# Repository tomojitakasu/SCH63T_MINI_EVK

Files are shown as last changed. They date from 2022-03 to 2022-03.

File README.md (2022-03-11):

# **SCHA63T_MINI_EVK**

## **Overview**

SCHA63T_MINI_EVK is a compact USB 2.0 interface board for Murata 6 DOF MEMS-IMU
SCHA63T-K03. The IMU sensor sampling timing can be synchronized by PPS and
NMEA inputs from an external clock source.

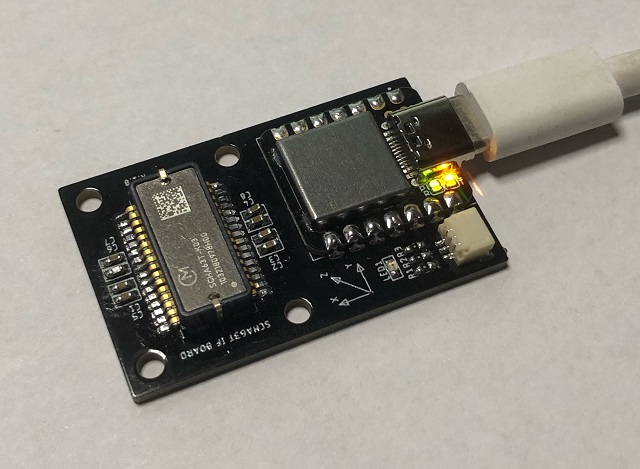
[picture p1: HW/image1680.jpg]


--------------------------------------------------------------------------------

## **Package Structure**
```
SCHA63T_MINI_EVK --+-- FW      Firmware source programs for Seeeduino XIAO
                   |           (ref [3])
                   +-- HW      I/F Board CAD data and parts list for hardware
                   |           (*.brd and *.sch are for Eagle)
                   +-- doc     SCHA63T-K03 documents (ref [1][2])
```

--------------------------------------------------------------------------------

## **Installation**

* Download and install Arduino IDE to your PC by "Software Step 1" in ref [3].

* Extract PocketSDR.zip to an appropriate directory <install_dir>.

* In Arduino IDE, execute menu File - Open... and select the sketch file
<install_dir>\SCHA63T_MIN_EVK\FW\Arduino\SCHA63T\SCHA63T.ino.

* Execute menu Sketch - Verify/Compile to compile the sketch.

* Connect SCHA63T_MINI_EVK board to the PC. Reset Seeeduino XIAO by shorting
the RST pins twice to enter the boot mode.

* Execute menu Tools - Board "Seeeduino XIAO" - Seeed SAMD (32-bits ARM
Cortex-M0+ and Cortex-M4) Boards - Seeeduino XIAO.

* Execute menu Tools - Port - COMxx (Seeeduino XIAO).

* Execute menu Sketch - Upload. If you see "Verify successful" in the IDE
message window, the firmware is properly written to the board.

--------------------------------------------------------------------------------

## **Operation**

* After connecting the SCHA63T_MINI_EVK board to the PC by USB cable, the board
automatically starts to output the IMU data as the following format via the USB
serial port. The initial output data rate is 100 Hz.
```
  $IMU,<t_sync>,<time>,<Rx>,<Ry>,<Rz>,<Ax>,<Ay>,<Az>,<temp>,<stat>*<CS>\r\n

  <t_sync>   : External time sync status (0:async, 1: PPS, 2: PPS + NMEA)
  <time>     : Time tag (s) (time of day in UTC for <t_sync> = 2)
  <Rx>,<Ry>,<Rz> : Gyroscope X,Y,Z data (deg/H)
  <Ax>,<Ay>,<Az> : Accelerometer X,Y,Z data (g)
  <temp>     : Sensor temperature (C)
  <stat>     : Sensor summary status (HEX) (0: OK, 1: error)
               bit 6-4: Rx,Ry,Rz, bit 2-0: Ax,Ay,Az
  <CS>       : Checksum same as NMEA
```

* By inputting PPS and NMEA signals via the external sync connector of the
board, the sampling timing of the IMU can be synchronized to the external
clock source. The pin assignment of the external sync connector is as follows.
Without the sync signals, the sampling is done by the internal clock.
```
  JST SH 3P (TOP VIEW)
  +-------+
  | pin 3 | <---- NMEA (3.3V, 9600 bps, GxGGA or GxRMC)
  | pin 2 | <---- PPS  (3.3V, rising edge)
  | pin 1 | ----- GND
  +-------+
```

* By sending commands to the board via the USB serial port, some IMU or
sampling parameters can be configured. The commands are as follows. The max
data rate is 200 Hz.
```
  reset                        : Reset device.
  device                       : Show device information.
  start                        : Start output data.
  stop                         : Stop output data.
  status                       : Show status.
  rate [<rate>]                : Set output data rate (Hz).
  range [<range_g> <range_a>]  : Select dynamic range gyro/accel.
                                 (0:300deg/H or 6g, 1:150deg/H or 1.5g)
  filter [<filt_g> <filt_a>]   : Select filter gyro/accel.
                                 (0:13Hz, 1:20Hz, 2:46Hz, 3:200Hz, 4:300Hz)
  table                        : Show cross-axis compensation table.
  read {DUE|UNO} [<addr>]      : Read device register(s). (addr:HEX)
  write {DUE|UNO} <addr> <val> : Write device register. (addr/val:HEX)
  debug [<level>]              : Set debug level. (0:no debug)
  help                         : Show command help.
```

--------------------------------------------------------------------------------

## **References**

[1] Murata, SCHA63T-K03 Data Sheet, Rev 1, 2021

[2] Murata, Assembly instructions for SCHA600 series Technical Note Rev 1.0, 2021

[3] Seeed Wiki, Getting Started with Seeeduino XIAO
(https://wiki.seeedstudio.com/Seeeduino-XIAO)

--------------------------------------------------------------------------------

## **History**

- 2022-03-11  1.0  1st version

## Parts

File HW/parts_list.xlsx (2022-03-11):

No | Part | Value | Package | Supplier | Supplier Part Number | Digi-Key Part Number | URL
1 | IMU1 | SCHA63T-K03 | SOIC-32 | Murata | SCHA63T-K03-05 | 490-SCHA63T-K03-05CT-ND | https://www.digikey.jp/product-detail/ja/murata-electronics/SCHA63T-K03-05/490-SCHA63T-K03-05CT-ND/14309548
2 | U1 | MOUDLE-SEEEDUINO-XIAO | 21 x 17.8 mm, 14P-2.54 mm | Seeed | Seeediuino XIAO | - | https://wiki.seeedstudio.com/Seeeduino-XIAO/
3 | C1 | 1uF | C1608
4 | C2 | 1uF | C1608
5 | C3 | 100nF | C1608
6 | C4 | 1uF | C1608
7 | C5 | 1uF | C1608
8 | C6 | 100nF | C1608
9 | C7 | 1uF | C1608
10 | C8 | 1uF | C1608
11 | R1 | 1K | R1608
12 | R2 | 1K | R1608
13 | R3 | 1K | R1608
14 | LED1 | LED1608 | LED1608
15 | J1 | Conn Header SMD R/A 3P 1mm | 4.25 x 5.0 x 2.9 mm | JST | SM03B-SRSS-TB(LF)(SN) | 455-1803-1-ND | https://www.digikey.jp/product-detail/ja/jst-sales-america-inc/SM03B-SRSS-TB-LF-SN/455-1803-1-ND/926874

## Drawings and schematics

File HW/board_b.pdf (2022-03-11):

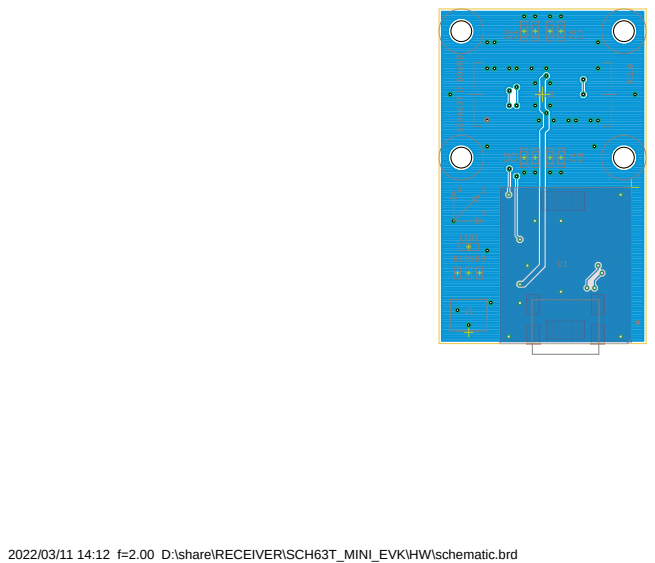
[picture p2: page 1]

2022/03/11 14:12 f=2.00 D:\share\RECEIVER\SCH63T_MINI_EVK\HW\schematic.brd

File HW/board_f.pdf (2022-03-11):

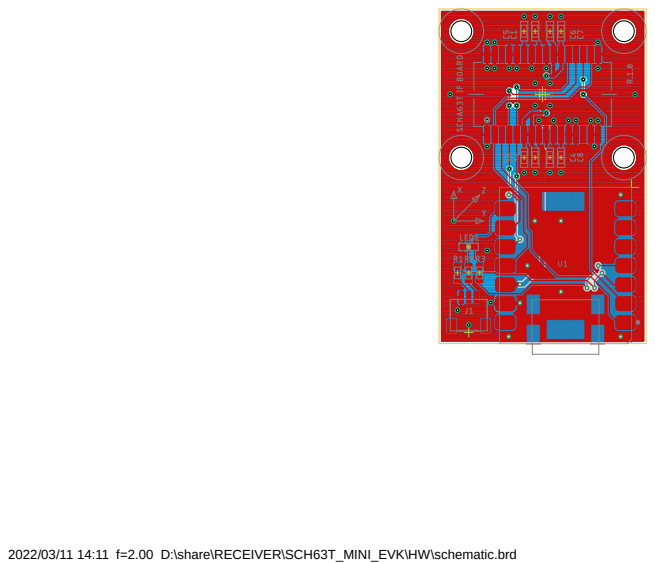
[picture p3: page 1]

2022/03/11 14:11 f=2.00 D:\share\RECEIVER\SCH63T_MINI_EVK\HW\schematic.brd

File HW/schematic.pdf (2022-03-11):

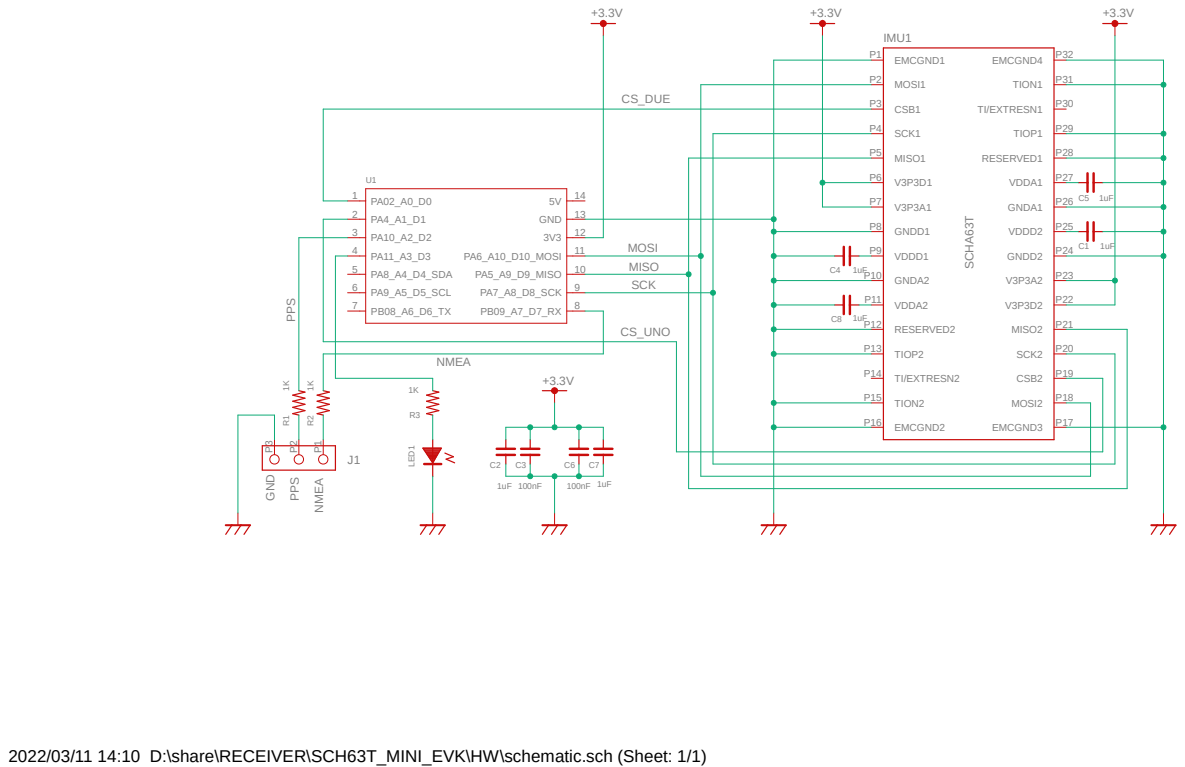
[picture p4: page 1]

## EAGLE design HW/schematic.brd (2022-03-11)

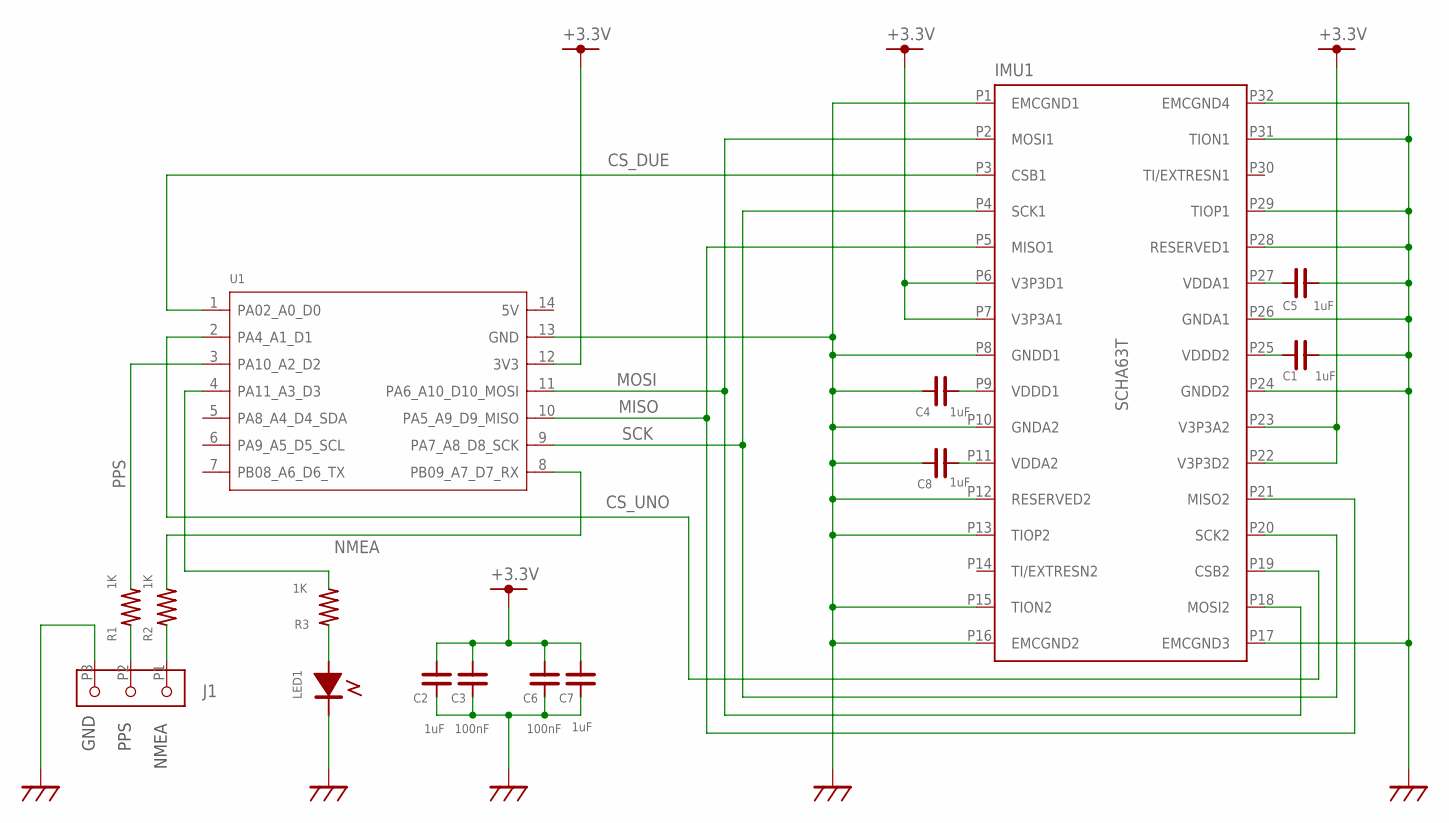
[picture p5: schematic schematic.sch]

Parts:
C1, C2, C4, C5, C7, C8: 1uF; C1608
C3, C6: 100nF; C1608
IMU1: SCHA63T; SOIC-32
J1: JST_SH_10_3P
LED1: LED1608; LED_1608
R1, R2, R3: 1K; C1608
U1: MOUDLE-SEEEDUINO-XIAO; MOUDLE14P-2.54-21X17.8MM

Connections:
+3.3V: C2.2, C3.2, C6.2, C7.2, IMU1.P6 (V3P3D1), IMU1.P7 (V3P3A1), IMU1.P22 (V3P3D2), IMU1.P23 (V3P3A2), U1.12 (3V3)
CS_DUE: IMU1.P3 (CSB1), U1.1 (PA02_A0_D0)
CS_UNO: IMU1.P19 (CSB2), U1.2 (PA4_A1_D1)
GND: C1.2, C2.1, C3.1, C4.1, C5.2, C6.1, C7.1, C8.1, IMU1.P1 (EMCGND1), IMU1.P8 (GNDD1), IMU1.P10 (GNDA2), IMU1.P12 (RESERVED2), IMU1.P13 (TIOP2), IMU1.P15 (TION2), IMU1.P16 (EMCGND2), IMU1.P17 (EMCGND3), IMU1.P24 (GNDD2), IMU1.P26 (GNDA1), IMU1.P28 (RESERVED1), IMU1.P29 (TIOP1), IMU1.P31 (TION1), IMU1.P32 (EMCGND4), J1.P3, LED1.2, U1.13 (GND)
MISO: IMU1.P5 (MISO1), IMU1.P21 (MISO2), U1.10 (PA5_A9_D9_MISO)
MOSI: IMU1.P2 (MOSI1), IMU1.P18 (MOSI2), U1.11 (PA6_A10_D10_MOSI)
unnamed: C5.1, IMU1.P27 (VDDA1)
unnamed: C1.1, IMU1.P25 (VDDD2)
unnamed: C4.2, IMU1.P9 (VDDD1)
unnamed: C8.2, IMU1.P11 (VDDA2)
unnamed: J1.P2, R1.1
unnamed: J1.P1, R2.1
unnamed: LED1.1 (+), R3.1
unnamed: R3.2, U1.4 (PA11_A3_D3)
NMEA: R2.2, U1.8 (PB09_A7_D7_RX)
PPS: R1.2, U1.3 (PA10_A2_D2)
SCK: IMU1.P4 (SCK1), IMU1.P20 (SCK2), U1.9 (PA7_A8_D8_SCK)

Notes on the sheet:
PPS
NMEA
GND

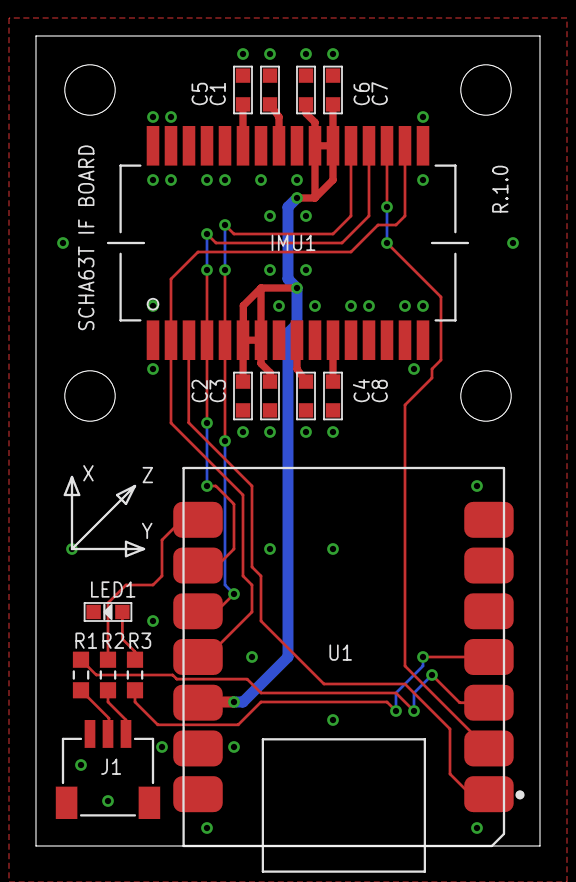
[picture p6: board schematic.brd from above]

Board: 2 copper layers, 28.0 x 45.0 mm, 15 parts (0 on the bottom side), 17 nets.

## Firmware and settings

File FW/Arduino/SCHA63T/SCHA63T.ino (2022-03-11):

/*
 *  Murata SCHA63T-K03 IMU I/F Board with Seeeduino XIAO
 * 
 *  References:
 *  [1] Murata, SCHA63T-K03: 6-DOF XYZ-Axis Gyroscope and xyz-Axis Accelerometer
 *      with digital SPI interface - Data Sheet, 2021 (https://www.murata.com)
 *  [2] Platform/Seeeduino XIAO (https://wiki.seeedstudio.com/Seeeduino-XIAO)
 *  [3] Arduino Language Reference (https://www.arduino.cc/reference)
 *
 *  Author:
 *  T.TAKASU
 *
 *  Histroy:
 *  2021-08-21  1.0.0  First version. 
 * 
 */

#include <SPI.h>
#include <TimerTC3.h> // library for Seeeduino XIAO

// -----------------------------------------------------------------------------

#define DEV_NAME     "SCHA63T-K03" // device name
#define FW_VER       "1.0.0"  // F/W version

#define CS_DUE       0        // Seeeduino XIAO PIN 1: (O) SPI CS DUE
#define CS_UNO       1        // Seeeduino XIAO PIN 2: (O) SPI CS UNO
#define PPS          2        // Seeeduino XIAO PIN 3: (I) PPS
#define LED_PPS      3        // Seeeduino XIAO PIN 4: (O) PPS LED
#define TEST_PIN     4        // Seeeduino XIAO PIN 5: (O) TEST PIN
#define LED_T        11       // Seeeduino XIAO LED T: (O) (blue)
#define LED_R        12       // Seeeduino XIAO LED R: (O) (blue)
#define LED_L        13       // Seeeduino XIAO LED L: (O) (orange)

#define REG_DUE_RZ   0x01     // SCHA63T register DUE Rate Z
#define REG_DUE_RY   0x03     // SCHA63T register UNO Rate Y
#define REG_DUE_RZ2  0x0B     // SCHA63T register UNO Rate Z2
#define REG_DUE_RY2  0x0D     // SCHA63T register UNO Rate Y2
#define REG_UNO_RX   0x01     // SCHA63T register DUE Rate X
#define REG_UNO_AX   0x04     // SCHA63T register DUE Acc X
#define REG_UNO_AY   0x05     // SCHA63T register DUE Acc Y
#define REG_UNO_AZ   0x06     // SCHA63T register DUE Acc Z
#define REG_UNO_RX2  0x0B     // SCHA63T register DUE Rate X2
#define REG_TEMP     0x07     // SCHA63T register temperature
#define REG_SUMSTAT  0x0E     // SCHA63T register summary status
#define REG_FILT_G   0x16     // SCHA63T register gyro filter control
#define REG_SYS_TEST 0x17     // SCHA63T register SYS_TEST
#define REG_RESET    0x18     // SCHA63T register reset control
#define REG_MODE     0x19     // SCHA63T register mode control
#define REG_FILT_A   0x1A     // SCHA63T register ACC filter control
#define REG_CID      0x1B     // SCHA63T register component ID
#define REG_TR2      0x1C     // SCHA63T register traceability 2
#define REG_TR0      0x1D     // SCHA63T register traceability 0
#define REG_TR1      0x1E     // SCHA63T register traceability 1
#define REG_SELBNK   0x1F     // SCHA63T register select bank
#define SCLK_RATE    10000000 // SCHA63T SPI SCLK rate (Hz)

#define SCALE_GYRO (1.0/80)   // SCHA63T gyro scale (deg/s/LSB) (nominal)
#define SCALE_ACCL (1.0/4905) // SCHA63T accelerometer scale (g/LSB) (nominal)
#define SCALE_TEMP (1.0/30)   // SCHA63T temperature scale (C/LSB)

#define HOST_RATE    115200   // HOST bitrate (bps)
#define NMEA_RATE    9600     // NMEA bitrate (bps)
#define PPS_MODE     RISING   // PPS interface mode (RISING or FALLING)
#define SAMP_RATE    200      // sampling rate (Hz)
#define MAX_RATE     200      // max data output rate (Hz)
#define MAX_TRY_INIT 3        // max try of device initializtion

#define LED_INTV     1000     // LED L blink interval (ms)
#define LED_DUTY     5        // LED blink duty-ratio

#define BYTE_L(x)    ((x) & 0xFF)
#define BYTE_H(x)    (((x) >> 8) & 0xFF)
#define ROUND(x)     (long)((x) + 0.5)

typedef void command_func_t(const char *); // command function type

// -----------------------------------------------------------------------------

volatile uint16_t data_rate;  // data output rate (Hz)
volatile double samp_intv;    // sampling interval (us)
volatile uint8_t samp_enable; // sampling enable (0:disable,1:enable)
volatile uint8_t time_sync;   // external time sync status (0:async,1:PPS,2:NMEA)
volatile uint8_t data_ready;  // data ready status (0:no,1:ready)
volatile uint32_t time_ms;    // data time (ms) (TOD in UTC: time_sync=NMEA)
volatile double data_gyro[3]; // data buffer gyro  {Rx, Ry, Rz} (deg/s)
volatile double data_accl[3]; // data buffer accel {Ax, Ay, Az} (g)
volatile uint16_t samp_count; // sample count in data buffer
volatile uint32_t pps_tick;   // tick of PPS signal
volatile uint8_t rang_sel[] = {0, 0}; // dynamic range selection gyro/accel
volatile uint8_t filt_sel[] = {2, 2}; // filter selection gyro/accel

volatile uint8_t debug_level = 0; // debug trace level (0:no debug)

char buff_command[128];       // command buffer
int p_command = 0;            // command buffer pointer
char buff_nmea[128];          // NMEA sentense buffer
int p_nmea = 0;               // NMEA sentense buffer pointer

// cross-axis compensation table ([1] 2.6)
float Cx[3][3] = {{1, 0, 0}, {0, 1, 0}, {0, 0, 1}}; // gyro
float Bx[3][3] = {{1, 0, 0}, {0, 1, 0}, {0, 0, 1}}; // accel

// STARTUP routine -------------------------------------------------------------
void setup() {  
  pinMode(CS_DUE, OUTPUT);
  pinMode(CS_UNO, OUTPUT);
  pinMode(PPS, INPUT_PULLUP);
  pinMode(TEST_PIN, OUTPUT);
  pinMode(LED_PPS, OUTPUT);
  
  digitalWrite(CS_DUE, HIGH);
  digitalWrite(CS_UNO, HIGH);
  digitalWrite(TEST_PIN, LOW);
  digitalWrite(LED_L, LOW);
  digitalWrite(LED_PPS, LOW);
  
  // start HOST serials
  Serial.begin(HOST_RATE);
  delay(100);
  
  // start SPI
  SPI.begin();
  SPI.beginTransaction(SPISettings(SCLK_RATE, MSBFIRST, SPI_MODE0));
  delay(100);
  
  // initialize device
  if (!init_device()) {
    init_err();
  }
  // initialize global variables
  init_vars();
  
  // start interval timer
  TimerTc3.initialize(ROUND(samp_intv));
  TimerTc3.attachInterrupt(timer_ISR);
  delay(100);
  
  // start PPS interrupts
  attachInterrupt(digitalPinToInterrupt(PPS), pps_ISR, PPS_MODE);
  delay(100);
  
  // start NMEA serials
  Serial1.begin(NMEA_RATE);
  delay(100);
  
  // enable sampling
  samp_enable = 1;
  
  digitalWrite(LED_L, HIGH);
}

// MAIN loop -------------------------------------------------------------------
void loop() {
  read_command();
  
  if (data_ready) {
    double gyro[3], accl[3], temp[2];
    uint8_t stat = read_stat(temp);
    
    noInterrupts();
    uint8_t t_sync = time_sync;
    uint32_t t_ms = time_ms;
    for (int i = 0; i < 3; i++) {
      gyro[i] = data_gyro[i];
      accl[i] = data_accl[i];
    }
    data_ready = samp_count = 0;
    interrupts();
    
    write_data(t_sync, t_ms, gyro, accl, temp, stat);
  }
  read_nmea();
}

// initialize SCHA63T ([1] Figure 7) -------------------------------------------
bool init_device() {
  trace(3, "init_device\r\n");
  
  // reset UNO/DUE
  write_reg(CS_UNO, REG_RESET, 1);
  write_reg(CS_DUE, REG_RESET, 1);
  delay(25);
  
  // read cross-axis compensation table
  read_axis_table();
  
  for (int i = 0; i < MAX_TRY_INIT; i++) {
    // set operation mode on
    write_reg(CS_UNO, REG_MODE, 0);
    write_reg(CS_DUE, REG_MODE, 0);
    write_reg(CS_DUE, REG_MODE, 0);
    delay(70);
    
    // set sensor dynamic ranges and filters
    set_rang_filt();
    
    // set EOI = 1
    write_reg(CS_UNO, REG_RESET, 2);
    write_reg(CS_DUE, REG_RESET, 2);
    
    if (test_init_end(CS_UNO) && test_init_end(CS_DUE)) {
      return true;
    }
    write_reg(CS_UNO, REG_RESET, 1); // reset UNO/DUE
    write_reg(CS_DUE, REG_RESET, 1);
    delay(25);
  }
  trace(2, "reset_device error\r\n");
  return false;
}

// read cross-axis compensation table ([1] 2.6) --------------------------------
void read_axis_table() {
  static const uint8_t reg_axis[] = // cross-axis compensation registers
    {0x0B, 0x13, 0x14, 0x15, 0x16, 0x17, 0x18, 0x1B, 0x1C};
  uint8_t reg_mode = REG_MODE;
  uint16_t data1[1], data2[9];
  
  trace(3, "read_axis_table\r\n");
  
  // enter test mode
  write_reg(CS_DUE, reg_mode, 0x10); // unlock code 010
  write_reg(CS_DUE, reg_mode, 0x08); // unlock code 001
  write_reg(CS_DUE, reg_mode, 0x20); // unlock code 100
  if (!read_reg(CS_DUE, &reg_mode, 1, data1) || (data1[0] & 0x7) != 0x7) {
    trace(2, "test mode enter error\r\n");
    return;
  }
  write_reg(CS_DUE, REG_SELBNK, 5); // change bank to 5
  
  if (read_reg(CS_DUE, reg_axis, 9, data2)) {
    Cx[0][0] = (int8_t)BYTE_L(data2[0]) / 4096.0f + 1.0f; // Cxx
    Cx[0][1] = (int8_t)BYTE_H(data2[0]) / 4096.0f;        // Cxy
    Cx[0][2] = (int8_t)BYTE_L(data2[1]) / 4096.0f;        // Cxz
    Cx[1][0] = (int8_t)BYTE_H(data2[1]) / 4096.0f;        // Cyx
    Cx[1][1] = (int8_t)BYTE_L(data2[2]) / 4096.0f + 1.0f; // Cyy
    Cx[1][2] = (int8_t)BYTE_H(data2[2]) / 4096.0f;        // Cyz
    Cx[2][0] = (int8_t)BYTE_L(data2[3]) / 4096.0f;        // Czx
    Cx[2][1] = (int8_t)BYTE_H(data2[3]) / 4096.0f;        // Czy
    Cx[2][2] = (int8_t)BYTE_L(data2[4]) / 4096.0f + 1.0f; // Czz
    Bx[0][0] = (int8_t)BYTE_H(data2[4]) / 4096.0f + 1.0f; // bxx
    Bx[0][1] = (int8_t)BYTE_L(data2[5]) / 4096.0f;        // bxy
    Bx[0][2] = (int8_t)BYTE_H(data2[5]) / 4096.0f;        // bxz
    Bx[1][0] = (int8_t)BYTE_L(data2[6]) / 4096.0f;        // byx
    Bx[1][1] = (int8_t)BYTE_H(data2[6]) / 4096.0f + 1.0f; // byy
    Bx[1][2] = (int8_t)BYTE_L(data2[7]) / 4096.0f;        // byz
    Bx[2][0] = (int8_t)BYTE_H(data2[7]) / 4096.0f;        // bzx
    Bx[2][1] = (int8_t)BYTE_L(data2[8]) / 4096.0f;        // bzy
    Bx[2][2] = (int8_t)BYTE_H(data2[8]) / 4096.0f + 1.0f; // bzz
    
    trace(3,"axis_reg=%04X %04X %04X %04X %04X %04X %04X %04X %04X\r\n",
      data2[0], data2[1], data2[2], data2[3], data2[4], data2[5], data2[6],
      data2[7], data2[8]);
  }
  write_reg(CS_DUE, REG_SELBNK, 0); // restore bank to 0
  write_reg(CS_DUE, REG_RESET, 1);  // reset DUE
  delay(25);
}

// set sensor dynamic ranges and filters ---------------------------------------
void set_rang_filt() {
  write_reg(CS_DUE, REG_FILT_G, // DUE: Rz2_DYN,Rz2_FILT,Ry2_DYN,Ry2_FILT
            ((uint16_t)rang_sel[0] << 14) | ((uint16_t)filt_sel[0] << 11) |
            ((uint16_t)rang_sel[0] <<  6) | ((uint16_t)filt_sel[0] <<  3));
  write_reg(CS_UNO, REG_FILT_G, // UNO: Rx2_DYN,Rx2_FILT
            ((uint16_t)rang_sel[0] << 14) | ((uint16_t)filt_sel[0] << 11));
  write_reg(CS_UNO, REG_FILT_A, // UNO: Ax_DYN,Ax_FILT,Ay_DYN,Ay_FILT,Az_DYN,Az_FILT
            ((uint16_t)rang_sel[1] << 11) | ((uint16_t)filt_sel[1] << 8) |
            ((uint16_t)rang_sel[1] <<  7) | ((uint16_t)filt_sel[1] << 4) |
            ((uint16_t)rang_sel[1] <<  3) | ((uint16_t)filt_sel[1] << 0));
  delay(525);
}

// test initialization completed -----------------------------------------------
bool test_init_end(uint8_t cs) {
  uint8_t req[4] = {0}, rsp[4] = {0};
  
  // read summary status register
  req[0] = REG_SUMSTAT << 2;
  req[3] = crc_spi(req);
  write_read_spi(cs, req, rsp);
  write_read_spi(cs, req, rsp);
  delay(3);
  write_read_spi(cs, req, rsp);
  return (rsp[0] & 0x3) == 0x1; // RS (return status) == 01
}

// device initialization error -------------------------------------------------
void init_err() {
  for (int i = 0;; i++) {
    digitalWrite(LED_L, i % 2 ? LOW : HIGH); // blink LED 10 Hz and halt
    delay(100);
  }
}

// initialize global variables -------------------------------------------------
void init_vars() { 
  trace(3, "init_vars\r\n");
  
  noInterrupts();
  data_rate = 100;
  samp_intv = 1000000.0 / SAMP_RATE;
  time_sync = data_ready = 0;
  time_ms = samp_count = 0;
  pps_tick = 0;
  interrupts();
}

// write sensor data to HOST ---------------------------------------------------
//
//  Data format
//
//  $IMU,<t_sync>,<time>,<Rx>,<Ry>,<Rz>,<Ax>,<Ay>,<Az>,<temp>,<stat>*<CS>\r\n
//
//  <t_sync>   : External time sync status (0:async, 1: PPS, 2: PPS + NMEA)
//  <time>     : Time tag (s) (time of day in UTC for <t_sync> = 2)
//  <Rx>,<Ry>,<Rz> : Gyroscope X,Y,Z data (deg/H)
//  <Ax>,<Ay>,<Az> : Accelerometer X,Y,Z data (g)
//  <temp>     : Sensor temperature (C)
//  <stat>     : Sensor summary status (HEX) (0: OK, 1: error)
//               bit 6-4: Rx,Ry,Rz, bit 2-0: Ax,Ay,Az
//  <CS>       : Checksum same as NMEA
//
void write_data(uint8_t t_sync, uint32_t t_ms, const double *gyro,
                const double *accl, const double *temp, uint8_t stat) {
    double gyro_c[3], accl_c[3];
    char buff[128], *p = buff;
    
    // cross-axis compensation ([1] 2.6)
    for (int i = 0; i < 3; i++) {
      gyro_c[i] = Cx[i][0] * gyro[0] + Cx[i][1] * gyro[1] + Cx[i][2] * gyro[2];
      accl_c[i] = Bx[i][0] * accl[0] + Bx[i][1] * accl[1] + Bx[i][2] * accl[2];
    }
    p += sprintf(p, "$IMU,%d,%.3f,%.4f,%.4f,%.4f,%.6f,%.6f,%.6f,%.1f,%02X",
           t_sync, t_ms * 0.001, gyro_c[0], gyro_c[1], gyro_c[2], accl_c[0],
           accl_c[1], accl_c[2], (temp[0] + temp[1]) * 0.5, stat);
    p += sprintf(p, "*%02X\r\n", cs_nmea(buff, p - buff));
    
    Serial.print(buff);
}

// interval timer ISR ----------------------------------------------------------
void timer_ISR() {
  uint32_t pps_time = micros() - pps_tick;
  uint32_t pps_intv = ROUND(samp_intv) * SAMP_RATE;
  uint32_t thres = ROUND(samp_intv) / 2;
  
  if (time_sync > 0 && pps_time > pps_intv + thres) {
    trace(3, "PPS signal lost: time=%.3f\r\n", time_ms * 0.001);
    time_sync = 0; // external time sync mode = async
  }
  if (time_sync == 0 || (pps_time > thres && pps_time < pps_intv - thres)) {
    // read sensor data
    read_sens();
  }
  if (pps_time >= pps_intv / LED_DUTY) {
    digitalWrite(LED_PPS, LOW);
  }
}

// PPS ISR ---------------------------------------------------------------------
void pps_ISR() {
  uint32_t tick = micros();
  uint32_t pps_time = tick - pps_tick;
  pps_tick = tick;
  
  // restart interval timer
  TimerTc3.restart();
  
  // read sensor data
  read_sens();
  
  if (time_sync == 0) {
    trace(3, "PPS signal detected: time=%.3f\r\n", time_ms * 0.001);
    time_sync = 1; // external time sync mode = PPS
  }
  time_ms = time_ms / 1000 * 1000;
  samp_count = 0;
  
  // adjust samping interval
  if (pps_time > 990000 && pps_time < 1010000) {
    samp_intv += ((double)pps_time / SAMP_RATE - samp_intv) * 0.1;
    TimerTc3.setPeriod(ROUND(samp_intv));
  }
  digitalWrite(LED_PPS, HIGH);
}

// read sensor data ------------------------------------------------------------
void read_sens() {
  static const uint8_t reg1[] = {REG_DUE_RZ2, REG_DUE_RY2};
  static const uint8_t reg2[] = {REG_UNO_RX2, REG_UNO_AX, REG_UNO_AY, REG_UNO_AZ};
  uint16_t data1[2], data2[4];
  
  time_ms = (time_ms + 1000 / SAMP_RATE) % 86400000;
  
  if (!samp_enable) return;
  
  // read sensor registers
  if (!read_reg(CS_DUE, reg1, 2, data1) || !read_reg(CS_UNO, reg2, 4, data2)) {
    return;
  }
  double gyro[3], accl[3];
  gyro[0] = (int16_t)data2[0] * SCALE_GYRO * (rang_sel[0] ? 0.5  : 1.0);
  gyro[1] = (int16_t)data1[1] * SCALE_GYRO * (rang_sel[0] ? 0.5  : 1.0);
  gyro[2] = (int16_t)data1[0] * SCALE_GYRO * (rang_sel[0] ? 0.5  : 1.0);
  accl[0] = (int16_t)data2[1] * SCALE_ACCL * (rang_sel[1] ? 0.25 : 1.0);
  accl[1] = (int16_t)data2[2] * SCALE_ACCL * (rang_sel[1] ? 0.25 : 1.0);
  accl[2] = (int16_t)data2[3] * SCALE_ACCL * (rang_sel[1] ? 0.25 : 1.0);
  samp_count++;
  
  for (int i = 0; i < 3; i++) {
    if (samp_count == 1) { // first sensor data
      data_gyro[i] = gyro[i];
      data_accl[i] = accl[i];
    }
    else { // average sensor data
      data_gyro[i] += (gyro[i] - data_gyro[i]) / samp_count;
      data_accl[i] += (accl[i] - data_accl[i]) / samp_count;
    }
  }
  if (time_ms % (1000 / data_rate) == 0) {
    data_ready = 1;
    
    if (samp_count != SAMP_RATE / data_rate) {
      trace(2, "samp_count error: time=%.3f samp_count=%d\r\n", time_ms * 0.001,
        samp_count);
    }
  }
  digitalWrite(LED_L, time_ms % LED_INTV < LED_INTV / LED_DUTY ? LOW : HIGH);
}

// read sensor status ----------------------------------------------------------
uint8_t read_stat(double *temp) {
  static const uint8_t reg1[] = {REG_TEMP, REG_SUMSTAT};
  static const uint8_t reg2[] = {REG_TEMP, REG_SUMSTAT};
  uint16_t data1[2], data2[2];
  
  // read status registers
  if (!read_reg(CS_DUE, reg1, 2, data1) || !read_reg(CS_UNO, reg2, 2, data2)) {
    return 0xFF; // error
  }
  temp[0] = 25.0 + (int16_t)data1[0] * SCALE_TEMP;
  temp[1] = 25.0 + (int16_t)data2[0] * SCALE_TEMP;
  
  // sensor summary status (0x00: all OK)
  return (uint8_t)(((~data2[1] >> 12) & 0x1) << 6 | // S_OK_Rx_F
                   ((~data1[1] >> 14) & 0x1) << 5 | // S_OK_Ry_F
                   ((~data1[1] >> 12) & 0x1) << 4 | // S_OK_Rz_F
                   ((~data2[1] >> 10) & 0x1) << 2 | // S_OK_Ax_F
                   ((~data2[1] >>  7) & 0x1) << 1 | // S_OK_Ay_F
                   ((~data2[1] >>  4) & 0x1) << 0); // S_OK_Az_F
}

// read registers of SCHA63T ---------------------------------------------------
bool read_reg(uint8_t cs, const uint8_t *reg, int n, uint16_t *data) {
  uint8_t req[4] = {0}, rsp[4];
  
  digitalWrite(TEST_PIN, HIGH);
  
  for (int i = 0; i <= n; i++) {
    if (i < n) {
      req[0] = (reg[i] & 0x1F) << 2; // reg read operation
      req[3] = crc_spi(req);
    }
    write_read_spi(cs, req, rsp);
    
    if (i > 0) {
      if (crc_spi(rsp) != rsp[3]) { // CRC error
        digitalWrite(TEST_PIN, LOW);
        trace(2, "read_reg CRC error: cs=%d reg=%02X\r\n", cs, reg[i]);
        return false;
      }
      data[i-1] = ((uint16_t)rsp[1] << 8) | rsp[2];
    }
  }
  digitalWrite(TEST_PIN, LOW);
  return true;
}

// write register of SCHA63T ---------------------------------------------------
bool write_reg(uint8_t cs, uint8_t reg, uint16_t data) {
  uint8_t req[4], rsp[4];
  
  req[0] = (uint8_t)0x80 | ((reg & 0x1F) << 2); // reg write operation
  req[1] = (uint8_t)BYTE_H(data);
  req[2] = (uint8_t)BYTE_L(data);
  req[3] = crc_spi(req);
  write_read_spi(cs, req, rsp);
  
  req[0] = (reg & 0x1F) << 2; // reg read operation
  req[1] = req[2] = 0;
  req[3] = crc_spi(req);
  write_read_spi(cs, req, rsp);
  
  if (crc_spi(rsp) != rsp[3]) {
    trace(2, "write_reg CRC error: cs=%d reg=%02X\r\n", cs, reg);
    return false;
  }
  return true;
}

// write and read 32 bit SPI frame ---------------------------------------------
void write_read_spi(uint8_t cs, const uint8_t *req, uint8_t *rsp) {
  
  digitalWrite(cs, LOW);
  rsp[0] = SPI.transfer(req[0]);
  rsp[1] = SPI.transfer(req[1]);
  rsp[2] = SPI.transfer(req[2]);
  rsp[3] = SPI.transfer(req[3]);
  digitalWrite(cs, HIGH);
  
  trace(4, "read_spi: cs=%d req=%02X%02X%02X%02X rsp=%02X%02X%02X%02X\r\n",
    cs, req[0], req[1], req[2], req[3], rsp[0], rsp[1], rsp[2], rsp[3]);
}

// SPI frame CRC of SCHA63T ([1] 5.1.6) ----------------------------------------
uint8_t crc_spi(const uint8_t *data) {
  uint8_t crc = 0xFF;
  
  for (int i = 0; i < 3; i++) {
    for (int j = 7; j >= 0; j--) {
      uint8_t bit = crc >> 7;
      crc <<= 1;
      if (bit ^ ((data[i] >> j) & 0x01)) crc ^= 0x1D;
    }
  }
  return (uint8_t)~crc;
}

// read command ----------------------------------------------------------------
void read_command() {
  int c;
  
  while ((c = Serial.read()) != -1) { // read HOST serial
    if (p_command >= sizeof(buff_command) - 1) {
      p_command = 0;
      continue;
    }
    buff_command[p_command++] = (char)c;
    if (c == '\r' || c == '\n') {
      buff_command[p_command] = '\0';
      parse_command(buff_command);
      p_command = 0;
    }
  }
}

// parse command ---------------------------------------------------------------
void parse_command(const char *buff) {
  static const char *command[] = {
    "reset", "device", "start", "stop", "status", "rate", "range", "filter",
    "read", "write", "debug", "table", "help", ""
  };
  static const command_func_t *command_func[] = {
    command_reset, command_device, command_start , command_stop , command_status,
    command_rate , command_range , command_filter, command_read , command_write ,
    command_debug, command_table , command_help
  };
  trace(3, "parse_command: buff=%s\r\n", buff);
  
  for (int i = 0; *command[i]; i++) {
    if (strncmp(buff, command[i], strlen(command[i]))) continue;
    command_func[i](buff);
    return;
  }
  trace(0, "> command error: %s\r\n", buff);
}

// command - reset -------------------------------------------------------------
void command_reset(const char *buff) {
  uint8_t ena = samp_enable;
  samp_enable = 0;
  init_device();
  init_vars();
  samp_enable = ena;
}

// command - device ------------------------------------------------------------
void command_device(const char *buff) {
  static const uint8_t reg[] = {REG_CID, REG_TR2, REG_TR0, REG_TR1};
  uint16_t data[4];
   
  if (!read_reg(CS_UNO, reg, 4, data)) {
    trace(0, "> device register read error\r\n");
  }
  else {
    trace(0, "> %-16s: %s\r\n", "device name", DEV_NAME);
    trace(0, "> %-16s: %s\r\n", "F/W version", FW_VER);
    trace(0, "> %-16s: %d\r\n", "component ID", data[0]);
    trace(0, "> %-16s: %05d%X%04XH00\r\n", "serial number", data[3],
      (data[1] >> 8) & 0xF, data[2]);
  }
}

// command - start -------------------------------------------------------------
void command_start(const char *buff) {
  samp_enable = 1;
}

// command - stop --------------------------------------------------------------
void command_stop(const char *buff) {
  samp_enable = 0;
}
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
